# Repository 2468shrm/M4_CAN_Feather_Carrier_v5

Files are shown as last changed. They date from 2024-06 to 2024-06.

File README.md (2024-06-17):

# M4_CAN_Feather_Carrier_v5

## Board Layout
![alt text]()

## Changes from Previous M4 Carrier Boards

This board has undergone multiple changes from previous versions of thie board, including, but not limite to:
- The level shifter for the DIOs was changed to the TXS0104B from the TXB version
  - The TXS version includes built-in pull ups and works considerably more reliably
- LEDs were added to indicate the logical state of the DIOs
  - An LED was added to each DIO as well as the level shifter enable
- The unity gain opamp was chaged to the LMV324AIDR which is a rail-to-rail version of the prior opamp
- One Qwiic/STEMMA port is removed (leaving 3)
- A MicroSD socket is added and extended to the SPI network (which now comprises of the Ethernet FeatherWing and the MicroS socket)
- A DC-DC converter is adde to the PCB replacing the Weewoodday module (woohoo)
- Cost reduced
  - Replaced many components with JLCPCB "Basic Parts" to reduce the Extended Parts costs
  - Many are 0603 devices for use with JLCPCB's PCBA service
- Updated the silkscreen to congratulate Unni Peri's graduation (the team will miss her contributions in the future, we're sure)

A PDF copy of the schematic [here](https://github.com/2468shrm/M4_CAN_Feather_Carrier_v3/blob/main/Images/Schematic.pdf).

## Checkout Status

This board has bot been fabbed yet.

Not yet tested:
- Everything :)

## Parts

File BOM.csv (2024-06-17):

Comment | Designator | Footprint | LCSC
470u | C1 | Appreciate:CAPAE830X1050N | C340767
470u | C26 | Appreciate:CAPAE830X1050N | C340767
10uF | C2 | Capacitor_SMD:C_0603_1608Metric | C96446
0.1u | C20 | Capacitor_SMD:C_0603_1608Metric | C14663
0.1u | C21 | Capacitor_SMD:C_0603_1608Metric | C14663
0.1u | C22 | Capacitor_SMD:C_0603_1608Metric | C14663
0.1u | C23 | Capacitor_SMD:C_0603_1608Metric | C14663
10u | C24 | Capacitor_SMD:C_0603_1608Metric | C96446
10u | C25 | Capacitor_SMD:C_0603_1608Metric | C96446
220nF | C3 | Capacitor_SMD:C_0603_1608Metric | C21120
1uF | C4 | Capacitor_SMD:C_0603_1608Metric | C59302
100nF | C5 | Capacitor_SMD:C_0603_1608Metric | C14663
100nF | C9 | Capacitor_SMD:C_0603_1608Metric | C14663
6.8pF | C6 | Capacitor_SMD:C_0603_1608Metric | C1679
22uF | C7 | Capacitor_SMD:C_0805_2012Metric | C45783
22uF | C8 | Capacitor_SMD:C_0805_2012Metric | C45783
LED | D1 | LED_SMD:LED_0603_1608Metric | C2286
LED | D2 | LED_SMD:LED_0603_1608Metric | C2286
LED | D3 | LED_SMD:LED_0603_1608Metric | C2286
LED | D4 | LED_SMD:LED_0603_1608Metric | C2286
LED | D8 | LED_SMD:LED_0603_1608Metric | C2286
LED | D102 | LED_SMD:LED_0603_1608Metric | C2286
LED | D103 | LED_SMD:LED_0603_1608Metric | C2286
SS54 | D6 | Appreciate:DO-214AC | C22452
SS54 | D101 | Appreciate:DO-214AC | C22452
FXL0630-3R3-M | L1 | Appreciate:FXL0630 | C167219
120 | R1 | Resistor_SMD:R_0603_1608Metric | C22787
120 | R2 | Resistor_SMD:R_0603_1608Metric | C22787
120 | R3 | Resistor_SMD:R_0603_1608Metric | C22787
120 | R4 | Resistor_SMD:R_0603_1608Metric | C22787
120 | R7 | Resistor_SMD:R_0603_1608Metric | C22787
100k | R101 | Resistor_SMD:R_0603_1608Metric | C25803
100k | R103 | Resistor_SMD:R_0603_1608Metric | C25803
24.9k | R102 | Resistor_SMD:R_0603_1608Metric | C25962
330 | R104 | Resistor_SMD:R_0603_1608Metric | C23138
1K2 | R105 | Resistor_SMD:R_0603_1608Metric | C22765
4K7 | R6 | Resistor_SMD:R_0603_1608Metric | C23162
LMR33630BDDA | U1 | Package_SO:Texas_HSOP-8-1EP_3.9x4.9mm_P1.27mm_ThermalVias | C544370
TXS0104EPW | U3 | Package_SO:TSSOP-14_4.4x5mm_P0.65mm | C44955
LMV324AIDR | U4 | Package_SO:SOIC-14_3.9x8.7mm_P1.27mm | C484732
74HC14 | U5 | Package_SO:TSSOP-14_4.4x5mm_P0.65mm | C2866133
STEMMA_I2C_QT | X1 | Connector_JST:JST_SH_BM04B-SRSS-TB_1x04-1MP_P1.00mm_Vertical | C495539
STEMMA_I2C_QT | X2 | Connector_JST:JST_SH_BM04B-SRSS-TB_1x04-1MP_P1.00mm_Vertical | C495539
STEMMA_I2C_QT | X4 | Connector_JST:JST_SH_BM04B-SRSS-TB_1x04-1MP_P1.00mm_Vertical | C495539
DM3D-SF | X3 | Appreciate:DM3DSF | C719027

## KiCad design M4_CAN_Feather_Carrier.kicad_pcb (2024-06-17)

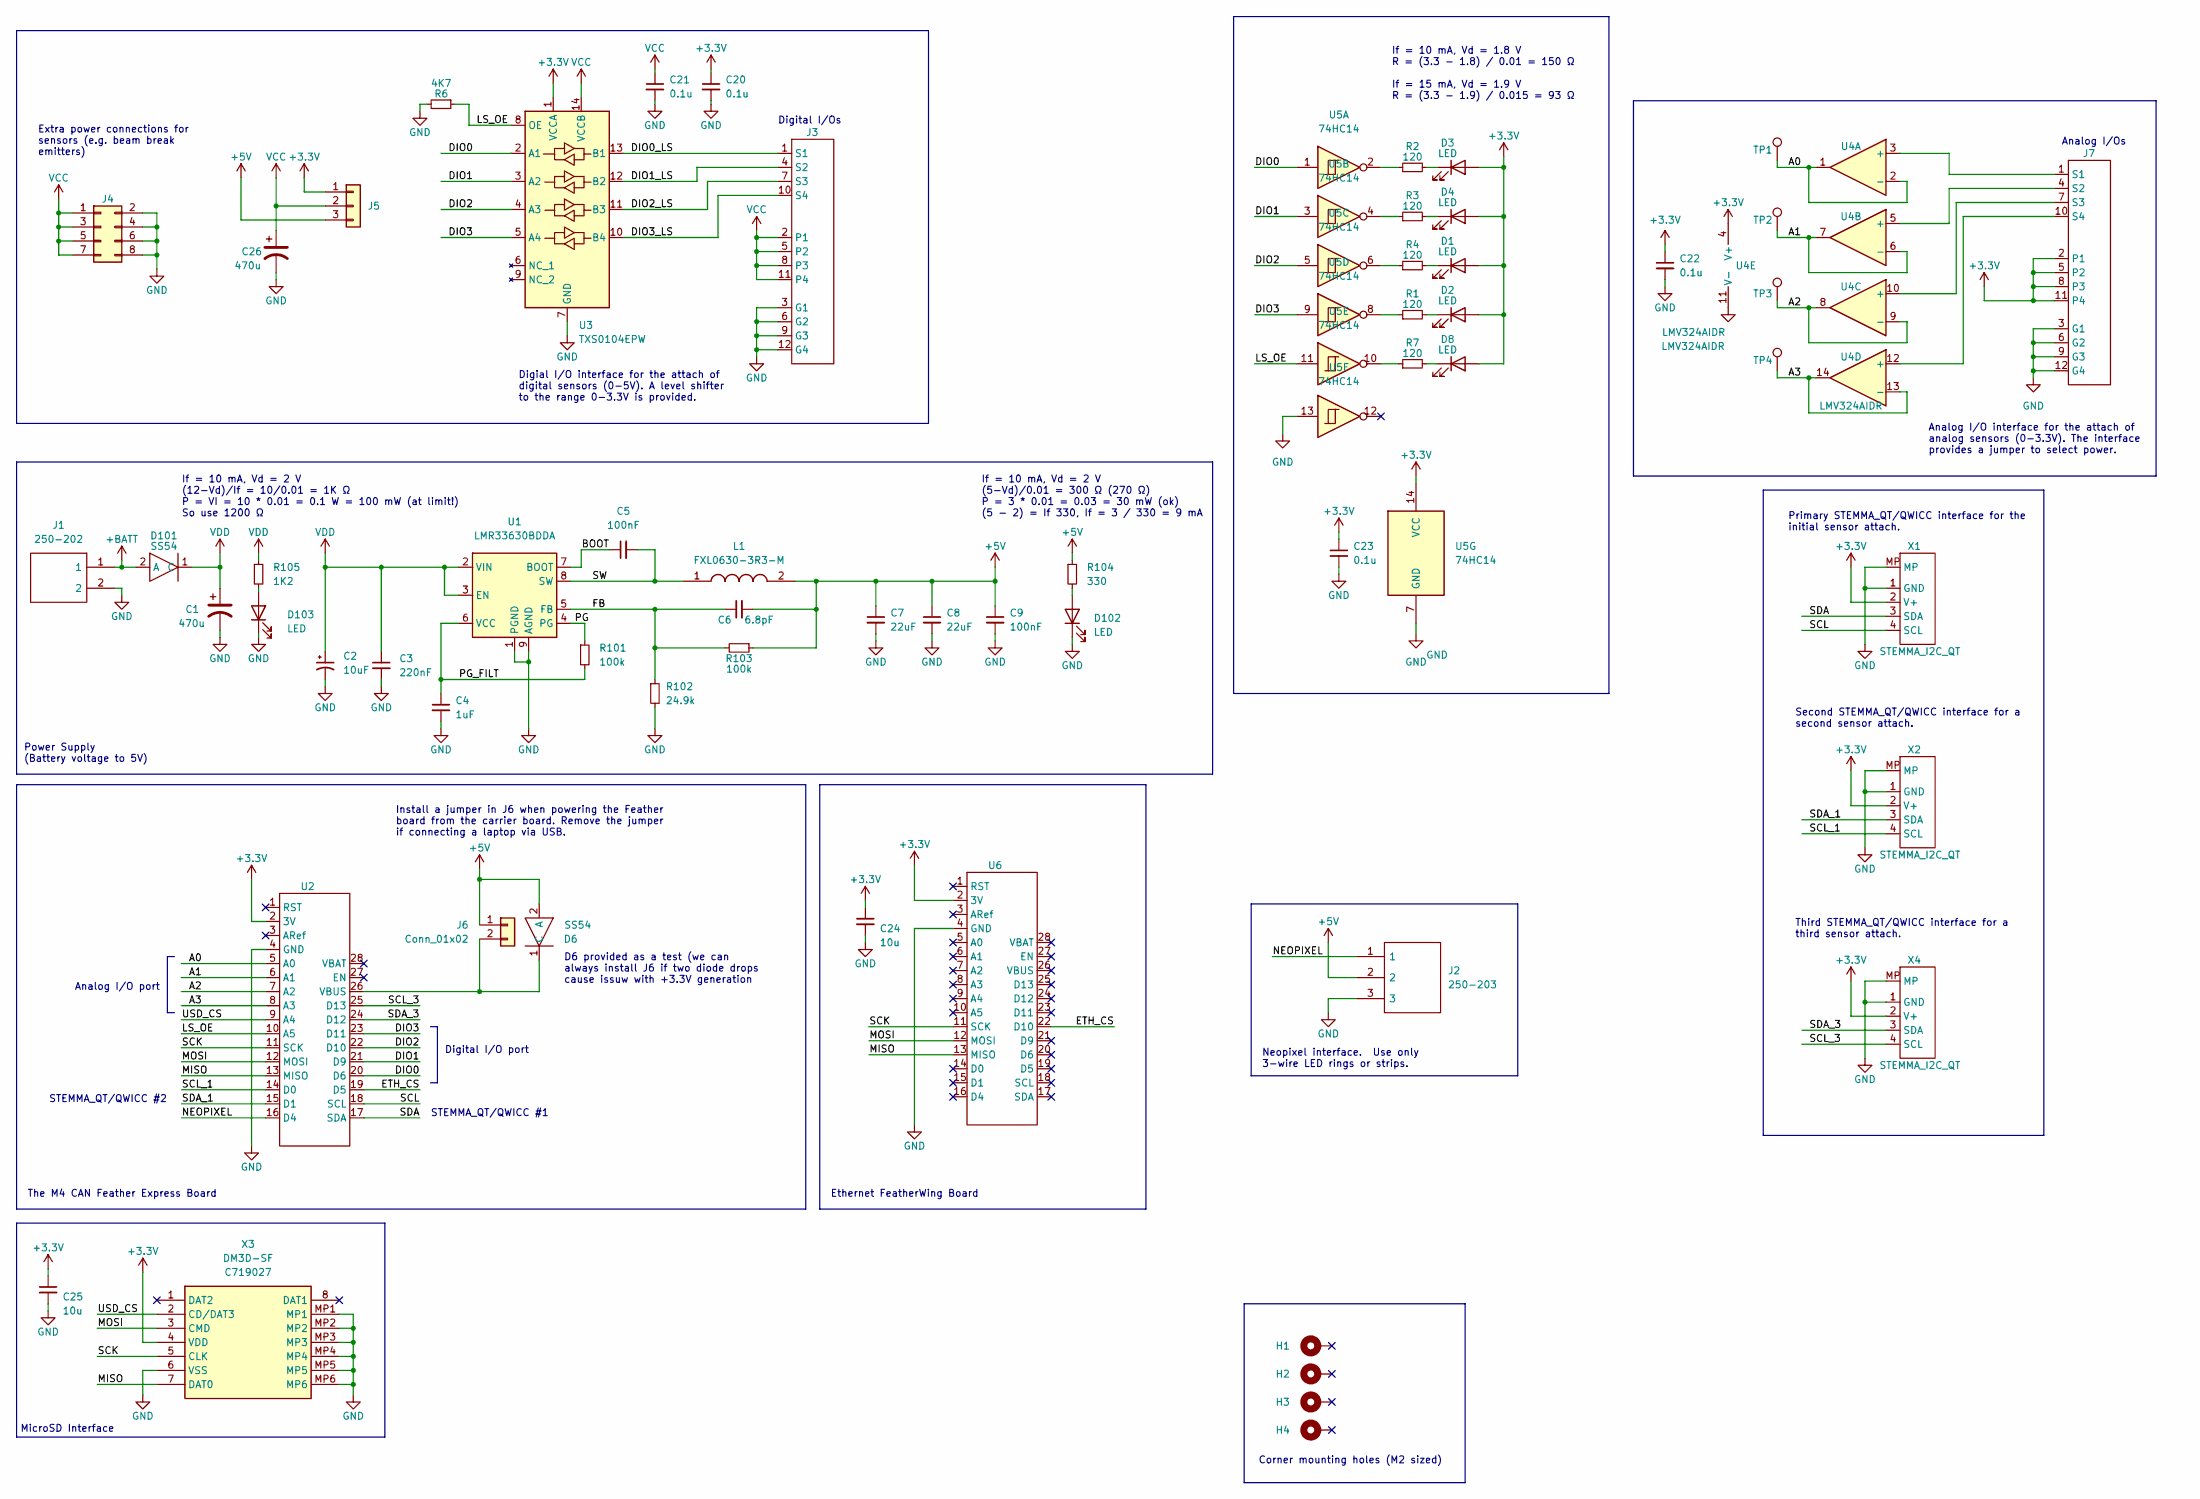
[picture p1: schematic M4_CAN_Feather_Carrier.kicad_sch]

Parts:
C1, C26: 470u; CAPAE830X1050N; LCSC C340767
C2: 10uF; C_0603_1608Metric; LCSC C96446
C3: 220nF; C_0603_1608Metric; LCSC C21120
C4: 1uF; C_0603_1608Metric; LCSC C59302
C5, C9: 100nF; C_0603_1608Metric; LCSC C14663
C6: 6.8pF; C_0603_1608Metric; LCSC C1679
C7, C8: 22uF; C_0805_2012Metric; LCSC C45783
C20, C21, C22, C23: 0.1u; C_0603_1608Metric; LCSC C14663
C24, C25: 10u; C_0603_1608Metric; LCSC C96446
D1, D2, D3, D4, D8, D102, D103: LED; LED_0603_1608Metric; LCSC C2286
D6, D101: SS54; DO-214AC; LCSC C22452
H1, H2, H3, H4: MountingHole_Pad; MountingHole_2.2mm_M2_DIN965_Pad
J1: 250-202; 250202; Manufacturer_Part_Number 250-202
J2: 250-203; 250-203_1; Manufacturer_Part_Number 250-203
J3, J7: conn_04_03; conn_04x03
J4: Conn_02x04_Odd_Even; PinHeader_2x04_P2.54mm_Vertical
J5: Conn_01x03; PinHeader_1x03_P2.54mm_Vertical
J6: Conn_01x02; PinHeader_1x02_P2.54mm_Vertical
L1: FXL0630-3R3-M; FXL0630; Manufacturer_Part_Number ASPI-0804T-150M-T; LCSC C167219
R1, R2, R3, R4, R7: 120; R_0603_1608Metric; LCSC C22787
R6: 4K7; R_0603_1608Metric; LCSC C23162
R101, R103: 100k; R_0603_1608Metric; LCSC C25803
R102: 24.9k; R_0603_1608Metric; LCSC C25962
R104: 330; R_0603_1608Metric; LCSC C23138
R105: 1K2; R_0603_1608Metric; LCSC C22765
TP1, TP2, TP3, TP4: TestPoint; TestPoint_Pad_1.5x1.5mm
U1: LMR33630BDDA; Texas_HSOP-8-1EP_3.9x4.9mm_P1.27mm_ThermalVias; LCSC C544370
U2, U6: Feather_M4_CAN_Express
U3: TXS0104EPW; TSSOP-14_4.4x5mm_P0.65mm; LCSC C44955
U4: LMV324AIDR; SOIC-14_3.9x8.7mm_P1.27mm; LCSC C484732
U5: 74HC14; TSSOP-14_4.4x5mm_P0.65mm; LCSC C2866133
X1, X2, X4: STEMMA_I2C_QT; JST_SH_BM04B-SRSS-TB_1x04-1MP_P1.00mm_Vertical; LCSC C495539
X3: DM3D-SF; DM3DSF; Manufacturer_Part_Number DM3D-SF; Mouser Part Number 798-DM3D-SF

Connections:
+3.3V: C20.1, C22.1, C23.1, C24.1, C25.1, D1.2 (A), D2.2 (A), D3.2 (A), D4.2 (A), D8.2 (A), J5.1, J7.2 (P1), J7.5 (P2), J7.8 (P3), J7.11 (P4), U2.2 (3V), U3.1 (VCCA), U4.4 (V+), U5.14 (VCC), U6.2 (3V), X1.2 (V+), X2.2 (V+), X3.4 (VDD), X4.2 (V+)
+5V: C6.2, C7.1, C8.1, C9.1, D6.2 (A), J2.2, J5.3, J6.1, L1.2, R103.1, R104.1
+BATT: D101.2 (A), J1.1
/A0: TP1.1, U2.5 (A0), U4.1, U4.2 (-)
/A1: TP2.1, U2.6 (A1), U4.6 (-), U4.7
/A2: TP3.1, U2.7 (A2), U4.8, U4.9 (-)
/A3: TP4.1, U2.8 (A3), U4.13 (-), U4.14
/BOOT: C5.1, U1.7 (BOOT)
/DIO0: U2.20 (D6), U3.2 (A1), U5.1
/DIO0_LS: J3.1 (S1), U3.13 (B1)
/DIO1: U2.21 (D9), U3.3 (A2), U5.3
/DIO1_LS: J3.4 (S2), U3.12 (B2)
/DIO2: U2.22 (D10), U3.4 (A3), U5.5
/DIO2_LS: J3.7 (S3), U3.11 (B3)
/DIO3: U2.23 (D11), U3.5 (A4), U5.9
/DIO3_LS: J3.10 (S4), U3.10 (B4)
/ETH_CS: U2.19 (D5), U6.22 (D10)
/FB: C6.1, R102.1, R103.2, U1.5 (FB)
/LS_OE: R6.1, U2.10 (A5), U3.8 (OE), U5.11
/MISO: U2.13 (MISO), U6.13 (MISO), X3.7 (DAT0)
/MOSI: U2.12 (MOSI), U6.12 (MOSI), X3.3 (CMD)
/NEOPIXEL: J2.1, U2.16 (D4)
/PG: R101.1, U1.4 (PG)
/PG_FILT: C4.1, R101.2, U1.6 (VCC)
/SCK: U2.11 (SCK), U6.11 (SCK), X3.5 (CLK)
/SCL: U2.18 (SCL), X1.4 (SCL)
/SCL_1: U2.14 (D0), X2.4 (SCL)
/SCL_3: U2.25 (D13), X4.4 (SCL)
/SDA: U2.17 (SDA), X1.3 (SDA)
/SDA_1: U2.15 (D1), X2.3 (SDA)
/SDA_3: U2.24 (D12), X4.3 (SDA)
/SW: C5.2, L1.1, U1.8 (SW)
/USD_CS: U2.9 (A4), X3.2 (CD/DAT3)
GND: C1.2, C2.2, C3.2, C4.2, C7.2, C8.2, C9.2, C20.2, C21.2, C22.2, C23.2, C24.2, C25.2, C26.2, D102.1 (K), D103.1 (K), J1.2, J2.3, J3.3 (G1), J3.6 (G2), J3.9 (G3), J3.12 (G4), J4.2, J4.4, J4.6, J4.8, J7.3 (G1), J7.6 (G2), J7.9 (G3), J7.12 (G4), R6.2, R102.2, U1.1 (PGND), U1.9 (AGND), U2.4 (GND), U3.7 (GND), U4.11 (V-), U5.7 (GND), U5.13, U6.4 (GND), X1.1 (GND), X1.MP, X2.1 (GND), X2.MP, X3.6 (VSS), X3.MP1, X3.MP2, X3.MP3, X3.MP4, X3.MP5, X3.MP6, X4.1 (GND), X4.MP
unnamed: D1.1 (K), R4.2
unnamed: D2.1 (K), R1.2
unnamed: D3.1 (K), R2.2
unnamed: D4.1 (K), R3.2
unnamed: D6.1 (C), J6.2, U2.26 (VBUS)
unnamed: D8.1 (K), R7.2
unnamed: D102.2 (A), R104.2
unnamed: D103.2 (A), R105.2
unnamed: J7.1 (S1), U4.3 (+)
unnamed: J7.4 (S2), U4.5 (+)
unnamed: J7.7 (S3), U4.10 (+)
unnamed: J7.10 (S4), U4.12 (+)
unnamed: R1.1, U5.8
unnamed: R2.1, U5.2
unnamed: R3.1, U5.4
unnamed: R4.1, U5.6
unnamed: R7.1, U5.10
VCC: C21.1, C26.1, J3.2 (P1), J3.5 (P2), J3.8 (P3), J3.11 (P4), J4.1, J4.3, J4.5, J4.7, J5.2, U3.14 (VCCB)
VDD: C1.1, C2.1, C3.1, D101.1 (C), R105.1, U1.2 (VIN), U1.3 (EN)

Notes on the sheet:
Corner mounting holes (M2 sized)
Digital I/Os
Install a jumper in J6 when powering the Feather board from the carrier board. Remove the jumper if connecting a laptop via USB.
Analog I/Os
Primary STEMMA_QT/QWICC interface for the initial sensor attach.
Extra power connections for sensors (e.g. beam break emitters)
Digial I/O interface for the attach of digital sensors (0-5V). A level shifter to the range 0-3.3V is provided.
The M4 CAN Feather Express Board
Second STEMMA_QT/QWICC interface for a second sensor attach.
If = 10 mA, Vd = 2 V (5-Vd)/0.01 = 300 Ω (270 Ω) P = 3 * 0.01 = 0.03 = 30 mW (ok) (5 - 2) = If 330, If = 3 / 330 = 9 mA
Digital I/O port
MicroSD Interface
Analog I/O port
STEMMA_QT/QWICC #1
If = 10 mA, Vd = 2 V (12-Vd)/If = 10/0.01 = 1K Ω P = VI = 10 * 0.01 = 0.1 W = 100 mW (at limit!) So use 1200 Ω
STEMMA_QT/QWICC #2
Analog I/O interface for the attach of analog sensors (0-3.3V). The interface provides a jumper to select power.
Neopixel interface. Use only 3-wire LED rings or strips.
Power Supply (Battery voltage to 5V)
Ethernet FeatherWing Board
D6 provided as a test (we can always install J6 if two diode drops cause issuw with +3.3V generation
Third STEMMA_QT/QWICC interface for a third sensor attach.
If = 10 mA, Vd = 1.8 V R = (3.3 - 1.8) / 0.01 = 150 Ω If = 15 mA, Vd = 1.9 V R = (3.3 - 1.9) / 0.015 = 93 Ω

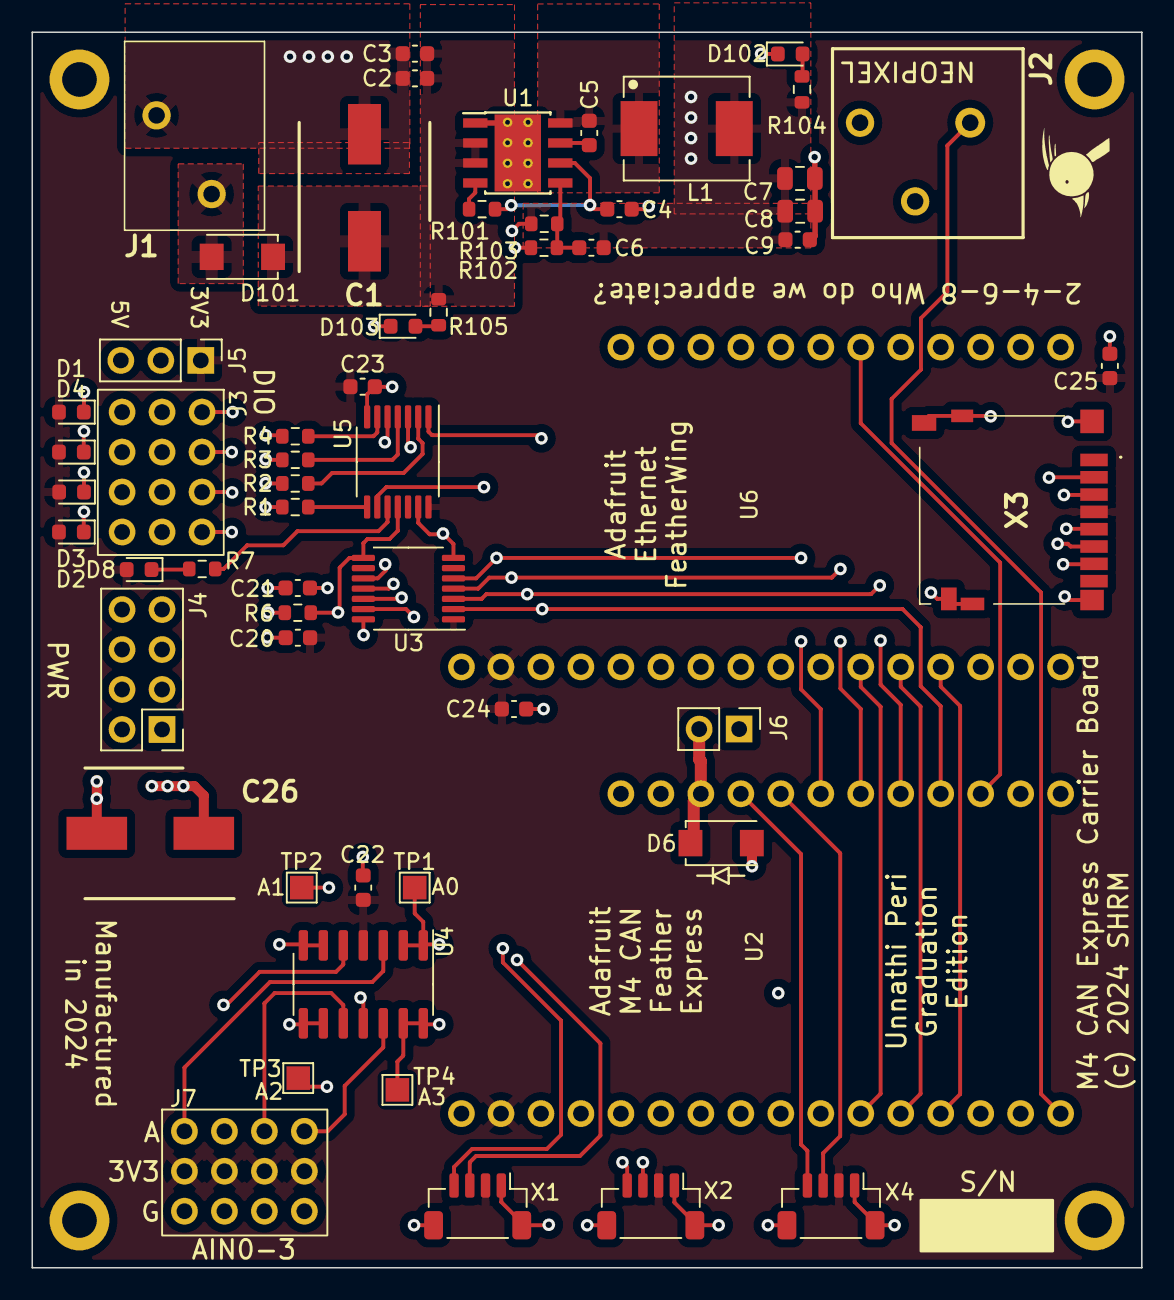
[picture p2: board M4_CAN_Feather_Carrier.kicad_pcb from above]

Board: 4 copper layers, 70.5 x 78.5 mm, 62 parts (0 on the bottom side), 53 nets.

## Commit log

2024-06-17 board files (KiCAD)
    [M4_CAN_Feather_Carrier.kicad_pcb, M4_CAN_Feather_Carrier.kicad_sch]
2024-06-17 BOM and component position files for JLCPCB fabrication and assembly
    [BOM.csv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]
2024-06-17 STEP file as generated by KiCAD

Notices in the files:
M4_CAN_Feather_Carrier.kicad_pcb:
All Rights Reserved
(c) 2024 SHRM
